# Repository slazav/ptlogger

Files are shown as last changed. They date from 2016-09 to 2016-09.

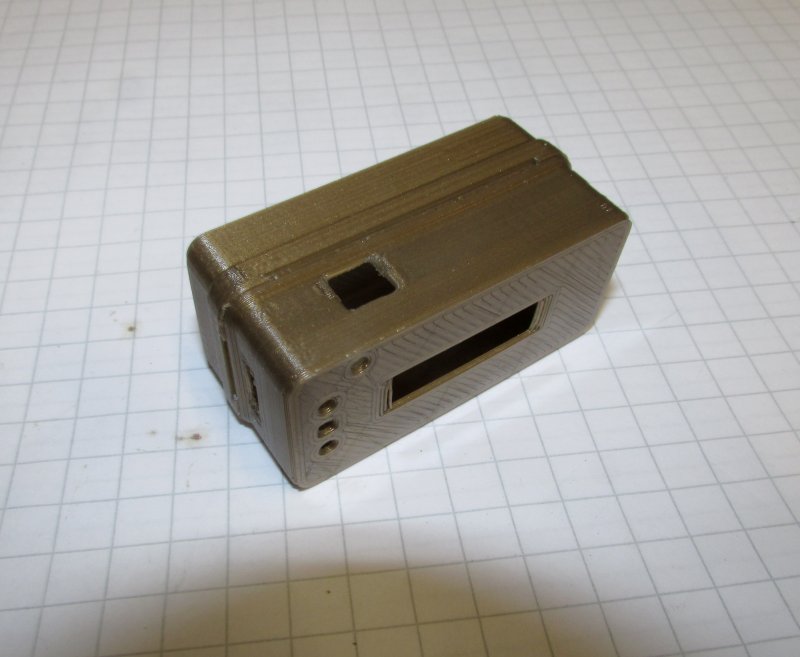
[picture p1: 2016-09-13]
box3d/pics/_1864.jpg

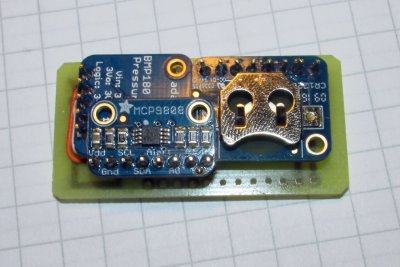
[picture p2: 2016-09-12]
pcb/pics/_1814.jpg

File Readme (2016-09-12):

Pressure + temperature logger based on Adafruit feather.

parts:
  Adafruit feather 32u4 Adalogger (main board + SD-card)
  FeatherWing OLED 128x32 (display + 3 buttons)
  BMP180 breakout (pressure + temperature + altitude sensor)
  MCP9808 breakout (temperature sensor)
  DS3231 breakout (real time clock)
  + connectors
  + self-made PCB (see pcb folder)
  + box (see box3d folder)

Arduino libraries:
  Wire              (I2C)
  SPI + SD          (SD-card)
  Adafruit_BMP085_U (BMP180)
  Adafruit-GFX      (graphics) -- Not needed, use local smaller version instead
  Adafruit_SSD1306  (display)  -- Not needed, use local smaller version instead
  Adafruit_MCP9808  (MCP9808) -- Not needed, use low-level I2C instead
  RTClib            (DS3231)  -- Not needed, use low-level I2C instead

All libraries workes, but program size is too large if all of them are included.
Using a simplified local version of Adafruit-GFX + Adafruit_SSD1306 solves this problem

assembling:

It is good to use connectors between main board, display board and sensor board.
Then you can easily debug the device, fix it, or use the main board for something else.
Size of the device is larger in this case.
I used connectors for display but soldered the sensor board.

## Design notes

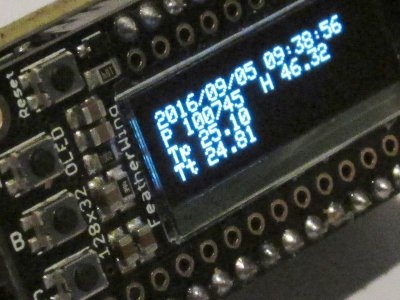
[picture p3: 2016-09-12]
pcb/pics/_1824a.jpg

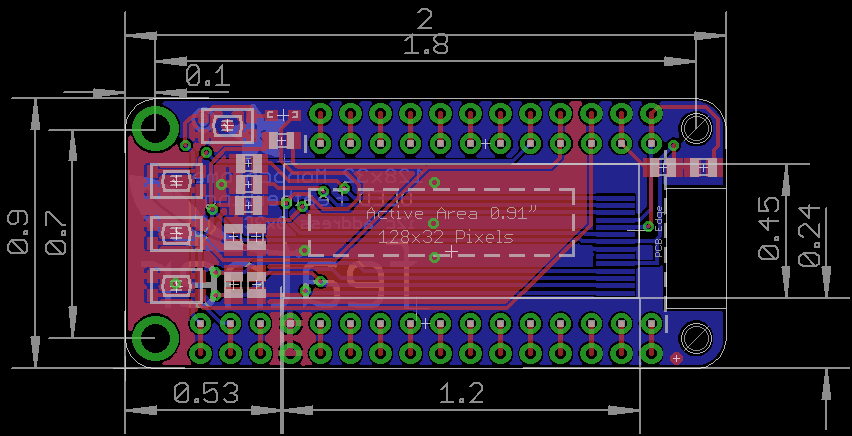
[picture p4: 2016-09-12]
pcb/feather_fabprint.png

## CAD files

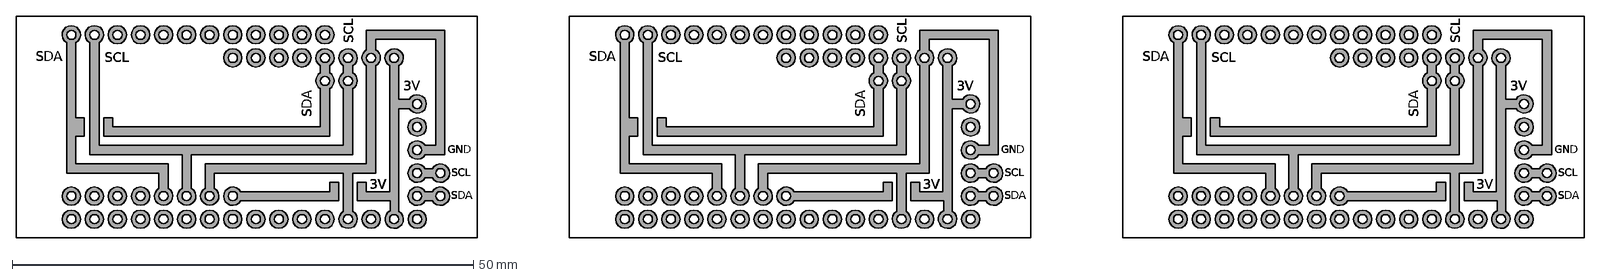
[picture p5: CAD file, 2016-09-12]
pcb/pcb.dxf
SDA
3V
SCL
GND

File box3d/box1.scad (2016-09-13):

i2m=25.4;

T = 0.8;
dT = 0.02;
// device body (inverted)
L=2*i2m + 0.15;
W=0.9*i2m + 0.15;
R=0.1*i2m;
H=14;
// buttons
Xb = [-6.6,-8.3,-8.3,-8.3]*i2m/10;
Yb = [-3.6,-1.7,0,1.7]*i2m/10;
Rb = [1,1,1,1]*1.25;
Wb = 2.5;
// screen
Ls = 0.91*i2m;
Ws = 0.25*i2m;
Xs = -0.4*i2m;
Ys = -0.16*i2m;
Rs = 0.5;
// USB
Zu = 7.75;
Hu = 2;
Wu = 7;
Ru = 0.5;
//sd-card
Zsd = 7.75;
Hsd = 2;
Wsd = 11.5;
Rsd = 0.5;
//power
Zp = 5;
Hp = 5.2;
Wp = 6;
Rp = 0.5;
Xp = L/2-11;

use <inc.scad>;

module inner_part(){
      rbox(L,W,H+dT,R); //body
      // buttons
      for (i=[0:len(Xb)-1]){
        translate([Xb[i],Yb[i],dT]) rotate([0,180])
          rrbox(Wb,Wb,T+2*dT,Rb[i],3,2.5);
      }
      // screen
      translate([0,0,dT]) rotate([0,180])
        rrbox(Ls,Ws,T+2*dT,Rs,1.2,1.5);
      // usb
      translate([-L/2+dT,0, Zu+Hu/2]) rotate([0,-90])
        rrbox(Hu,Wu,T+2*dT,Ru,1.7,1.7);
      // sd-card
      translate([L/2-dT,0, Zsd+Hsd/2]) rotate([0,90])
        rrbox(Hsd,Wsd,T+2*dT,Rsd,1.7,1.7);
      // power
      translate([-Xp,-W/2+dT, Zp+Hp/2]) rotate([0,90,-90])
        rrbox(Hp,Wp,T+2*dT,Rp,1.1,1.4);
}


difference(){
  union(){
    half_box(L,W,H,R,T);
    translate([0,0,H-4*T]) half_box(L+2*T,W+2*T,T,R+T,T);
  }
  inner_part();
}

//        %rbox(Hp,Wp,T+2*dT,Rp,1.4,1.4);
//      rrbox(Hp,Wp,T+2*dT,Rp,1.4,1.4);

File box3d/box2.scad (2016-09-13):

i2m=25.4;

T = 0.8;
dT = 0.02;
// device body (inverted)
L=2*i2m +0.15;
W=0.9*i2m + 0.15;
R=0.1*i2m;
H=8;
dH = 2;

use <inc.scad>

module inner_part(){
  rbox(L,W,H+dH+4*T+dT,R); //body
  translate([0,0,H])
    rbox(L+2*T+0.1,W+2*T+0.1,dH+4*T+dT,R+T);
  // holes
  nh=4;
  for (i=[-nh:nh]){
    translate([L/4,W/4*i/nh,dT]) rotate([180])
      rbox(L*1/3*(1-pow(i/nh,2)/4), T, T+2*dT, T/2);
  }
      
}

difference(){
  union(){
    half_box(L,W,H,R,T);
    translate([0,0,H-T]) half_box(L+2*T,W+2*T,dH+5*T,R+T,T);
  }
  inner_part();
}

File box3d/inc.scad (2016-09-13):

// flat sqare with rounded corners
module rsquare(L,W,R){
  // roundings
  for (x=[-1,1], y=[-1,1]){
    translate([x*(L/2-R), y*(W/2-R)])
      circle(r=R, $fn=100);
  }
  // body
  translate([0,0]){
    square([L-2*R,W], center=true);
    square([L,W-2*R], center=true);
  }
}

// same, but extruded into a box
module rbox(L,W,H,R, s=1){
  linear_extrude(height=H, scale=s) rsquare(L,W,R);
}

// rounded box with non-linear extruding
rri=5;
module rrbox(L,W,H,R, SL,SW){
  ddSL = pow(SL,2/rri/(rri-1));
  ddSW = pow(SW,2/rri/(rri-1));
  dH=H/rri;

  for (i=[0:rri-1]){
    dSL = pow(ddSL,i);
    dSW = pow(ddSW,i);
    L1=(i>0)? L*pow(ddSL, (i-1)*i/2):L;
    W1=(i>0)? W*pow(ddSW, (i-1)*i/2):W;
    R1=(i>0)? R*pow(ddSW, (i-1)*i/2):R;

    translate([0,0,i*dH])
    if (i<rri-1){ // avoid 0-walls
      g = 1.2; // overlap
      S = [1+g*(dSL-1),1+g*(dSW-1)];
      linear_extrude(height=dH*g, scale=S)
      rsquare(L1,W1,R1);
    }
    else {
      linear_extrude(height=dH, scale=[dSL,dSW])
      rsquare(L1,W1,R1);
    }
  }
}


// same, but with rounded bottom
module half_box(L,W,H,R,T){
  hull(){
    rbox(L+2*T,W+2*T,H,R+T);
    translate([0,0,-T])
      rbox(L,W,T,R);
  }
}

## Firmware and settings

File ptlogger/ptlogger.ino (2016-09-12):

#define USE_DISP 1
#define USE_CARD 1
#define USE_PRES 1
#define USE_TEMP 1
#define USE_RTC 1
#define NORMAL_MODE  1

#define BTNA 9
#define BTNB 6
#define BTNC 5
#define GLED  8
#define YLED  13
#define CARD  7
#define CARD_CS  4
#define OLED_RESET 4

#define ADDR_OLED 0x3C
#define ADDR_RTC    0x68
#define ADDR_PRES  0x77
#define ADDR_TEMP 0x18

#define MAXDISPCOUNT 60

#include <Arduino.h>

// include headers and define variables for all components:

// cf card:
#if USE_CARD
#include <SPI.h>
#include <SD.h>
File dataFile;
bool cfmode = false;
#endif

// display:
#if USE_DISP
#include "Adafruit_GFXm.h"
#include "Adafruit_SSD1306m.h"
Adafruit_SSD1306 display(OLED_RESET);
int16_t  dispcount=MAXDISPCOUNT; // counter for display-on state
#endif

// output functions for both display and cf:
void ppf(const char *txt, float f, uint8_t w){
#if USE_DISP
  display.print(txt);
  display.print(f,w);
#endif
#if USE_CARD
  if (dataFile){
     dataFile.print(" ");
     dataFile.print(f,w);
  }
#endif
}
void ppi(int f, uint8_t w, const char *txt){
  for (; w>0; w--){
    #if USE_DISP
    display.print( ( f/int(pow(10, w-1)))%10 );
    #endif
    #if USE_CARD
    dataFile.print( ( f/int(pow(10, w-1)))%10 );
    #endif
  }
  #if USE_DISP
  display.print(txt);
  #endif
  #if USE_CARD
  dataFile.print(txt);
  #endif
}

// thermometer:
#if USE_TEMP
#include <Wire.h>
#endif

// clock:
#if USE_RTC
#include <Wire.h>
static uint8_t bcd2bin (uint8_t val) { return val - 6 * (val >> 4); }
static uint8_t bin2bcd (uint8_t val) { return val + 6 * (val / 10); }
#endif

// pressure sensor:
#if USE_PRES
#include <Adafruit_BMP085_U.h>
Adafruit_BMP085_Unified PRESS;
float p0=101300;
#endif

/**********************************************/
// setup function
/**********************************************/
void setup()   {
  pinMode(BTNA, INPUT_PULLUP);
  pinMode(BTNB, INPUT_PULLUP);
  pinMode(BTNC, INPUT_PULLUP);
  pinMode(CARD, INPUT_PULLUP);
  pinMode(GLED, OUTPUT);
  pinMode(YLED, OUTPUT);

#if USE_RTC
  Wire.begin();
#endif

#if USE_TEMP
  Wire.begin();
   Wire.beginTransmission(ADDR_TEMP);
   Wire.write((byte)0x08);
   Wire.write((byte)0x03); // resolution 0.0625
   Wire.endTransmission();
#endif

#if USE_PRES
  PRESS.begin(BMP085_MODE_ULTRAHIGHRES);
//  PRESS.begin(BMP085_MODE_ULTRALOWPOWER);
#endif

#if USE_DISP
  display.begin(SSD1306_SWITCHCAPVCC, ADDR_OLED);
  display.display(); // show logo
#endif

#if USE_CARD
#endif
}

/**********************************************/
// loop function
/**********************************************/

#if NORMAL_MODE
void loop() {
  delay(1000);

  #if USE_DISP
    if (digitalRead(BTNB)==LOW) {
      if (dispcount)  dispcount=0;
      else dispcount = MAXDISPCOUNT;
    }
    if (dispcount) dispcount--;
  #endif

  #if USE_CARD
    if (digitalRead(BTNA)==LOW)   cfmode = !cfmode;
    if (cfmode)  {
       SD.begin(CARD_CS);
       dataFile = SD.open("data.txt", FILE_WRITE);
    }
   #endif

#if USE_DISP
  display.clearDisplay();
  display.setCursor(0,0);
#endif

 
  // get all information
  //time
  #if USE_RTC
  Wire.beginTransmission(ADDR_RTC);
  Wire.write((byte)0);
  Wire.endTransmission();
  Wire.requestFrom(ADDR_RTC, 7);
  uint8_t ss = bcd2bin(Wire.read() & 0x7F);
  uint8_t mm = bcd2bin(Wire.read());
  uint8_t hh = bcd2bin(Wire.read());
  Wire.read();
  uint8_t d = bcd2bin(Wire.read());
  uint8_t m = bcd2bin(Wire.read());
  uint16_t y = bcd2bin(Wire.read()) + 2000;
  // print
  ppi(y,4,"/");
  ppi(m,2,"/");
  ppi(d,2," ");
  ppi(hh,2,":");
  ppi(mm,2,":");
  ppi(ss,2,"");
    #if USE_DISP
    display.println();
    #endif
  #endif

  // pressure + temperature + altitude
  #define NAVRGS 20
  int i;
  float tmp;
  #if USE_PRES
  float p=0,  h, tp=0;  
  for (i=0; i<NAVRGS; i++){
    PRESS.getPressure(&tmp);
    p+=tmp;
    PRESS.getTemperature(&tmp);
    tp+=tmp;
  }
  p/=NAVRGS;
  tp/=NAVRGS;
     
  //PRESS.getPressure(&p);
  //PRESS.getTemperature(&tp);
  if (digitalRead(BTNC)==LOW)  p0=p;
  h = 44330.0 * (1.0 - pow(p /p0 , 0.1903));
  // print
  ppf("P ", p, 0);
  ppf("  H ", h, 2);
    #if USE_DISP
    display.println();
    #endif
  ppf("Tp ", tp, 2);
    #if USE_DISP
    display.println();
    #endif
  #endif

  //temperature (read register 0x05 from address ADDR_TEMP)
  #if USE_TEMP
  float tt=0;
  for (i=0; i<NAVRGS; i++){
    Wire.beginTransmission(ADDR_TEMP);
    Wire.write((uint8_t) 0x05);
    Wire.endTransmission();
    Wire.requestFrom((uint8_t)ADDR_TEMP, (uint8_t)2);
    int16_t tti = Wire.read();
    tti <<= 8;
    tti|= Wire.read();
    // convert to float
    tmp= float(tti & 0x0FFF)/16.0;
    if (tti & 0x1000) tmp-= 256;
    tt+=tmp;
  }
  tt/=NAVRGS;
  ppf(" ", tt, 2);
  #endif

#if USE_CARD
  if (dataFile) {
    #if USE_DISP
      display.setCursor(64,16);
      display.print("CF");
    #endif
    dataFile.println(); 
    dataFile.close();
  }
#endif

#if USE_DISP
  if (dispcount==0) display.clearDisplay();
  display.display();
#endif
}



#else
  // set time (use predefined values, set on button A press)
  void loop() {
   delay(1);
   if (digitalRead(BTNA)==LOW){

   uint8_t ss = 0;
   uint8_t mm = 36;
   uint8_t hh = 23;
   uint8_t d = 4;
   uint8_t m = 9;
   uint16_t y = 16;

    Wire.beginTransmission(ADDR_RTC);
    Wire.write((byte)0); // start at location 0
    Wire.write(bin2bcd(ss));
    Wire.write(bin2bcd(mm));
    Wire.write(bin2bcd(hh));
    Wire.write(bin2bcd(0));
    Wire.write(bin2bcd(d));
    Wire.write(bin2bcd(m));
    Wire.write(bin2bcd(y));
    Wire.endTransmission();

    // read i2c register
    Wire.beginTransmission(ADDR_RTC);
    Wire.write((byte)0xFF);
    Wire.endTransmission();
    Wire.requestFrom(ADDR_RTC, (byte)1);
    uint8_t statreg =  Wire.read() & ~0x80; // flip OSF bit

    // write i2c register
    Wire.beginTransmission(ADDR_RTC);
   Wire.write((byte)0xFF);
   Wire.write((byte)statreg);
   Wire.endTransmission();

      digitalWrite(YLED, HIGH);
      delay(200);
      digitalWrite(YLED, LOW);
   }
}
#endif

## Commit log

2016-09-12 working device + program
    [box1.scad, box2.scad, pcb.dxf]
2016-09-13 improve the box
    [box1.scad, box2.scad, inc.scad]
2016-09-13 box3d v.2
    [box1.scad, box2.scad, inc.scad]
